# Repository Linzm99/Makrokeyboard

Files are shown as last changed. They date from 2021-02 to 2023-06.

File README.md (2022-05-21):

# Makrokeyboard
Open Source Makrokeyboard based on Atmega32U4
Image Makrokeyboard wide

## Code

The Code for the Makrokeyboard was written for the Arduino IDE, which supports the Atmega32U4 as Arduino Leonardo/Pro Micro. For uploading "Arduino Leonardo" or "Arduino (Pro) Micro" should be selected as Board. The COM Port selector will show the Atmega32U4 as well.
Hint: If your Chip wasn't flashed with a bootloader you have to do that first. This requires soldering a ISP Connector and flashing via (for example) Arduino ISP. [Tutorial from Leon Anavi](https://www.youtube.com/watch?v=ToMrxnRNHM4)

Image Makrokeyboard close

## Parts

Following Parts are required:

- 1x USB-C-Connector
- 2x 5k1 Resistor 0805
- 1x FSMD050R
- 1x 0R Resistor
- 21x SK6812 rear mounted addressable LED
- 20x Diodes 0805
- 20x Keyboard Switches
- 1x 16MHz Quarz
- 1x Atmega32U4 TQFP44
- 6x 100nF 1206
- 2x 1uF 1206
- 2x 22pF 1206
- 21x 10k Resistor 0603
- 3x 22R 1206

Image Makrokeyboard top

Created by [Linze99](https://www.twitch.tv/linze99)

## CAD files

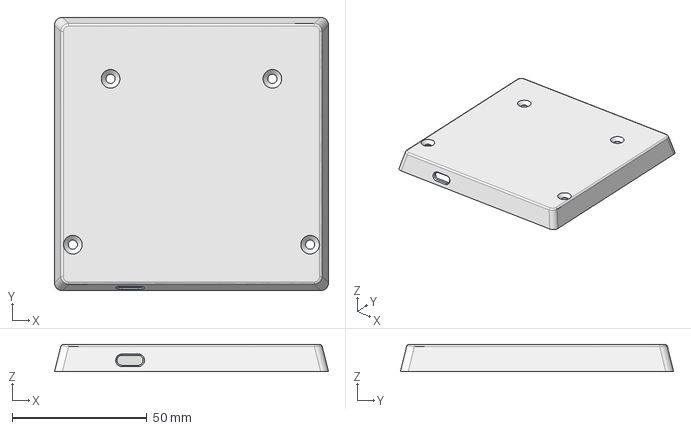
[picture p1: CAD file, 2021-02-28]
Case/gehäuse unten.FCStd
101.6 x 101.3 x 10.1 mm

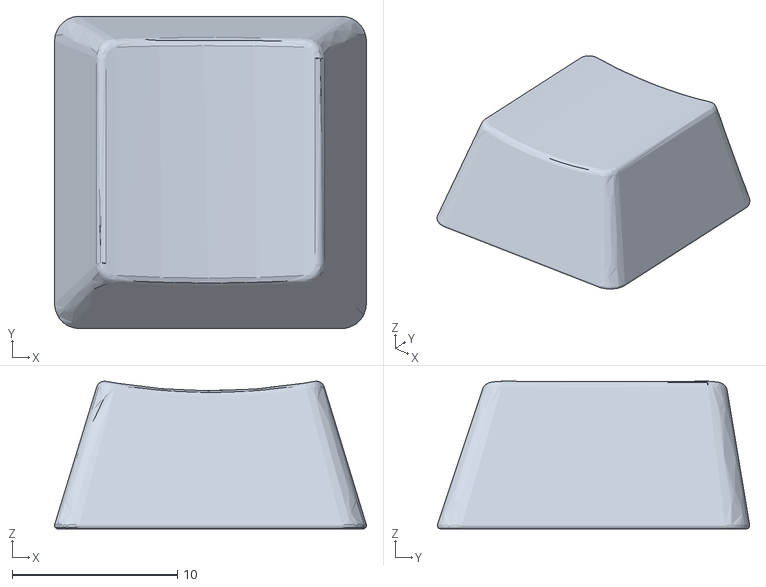
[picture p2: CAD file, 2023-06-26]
Keycaps/keycap_basic_thebrutzler.stl
18.9 x 18.9 x 8.93

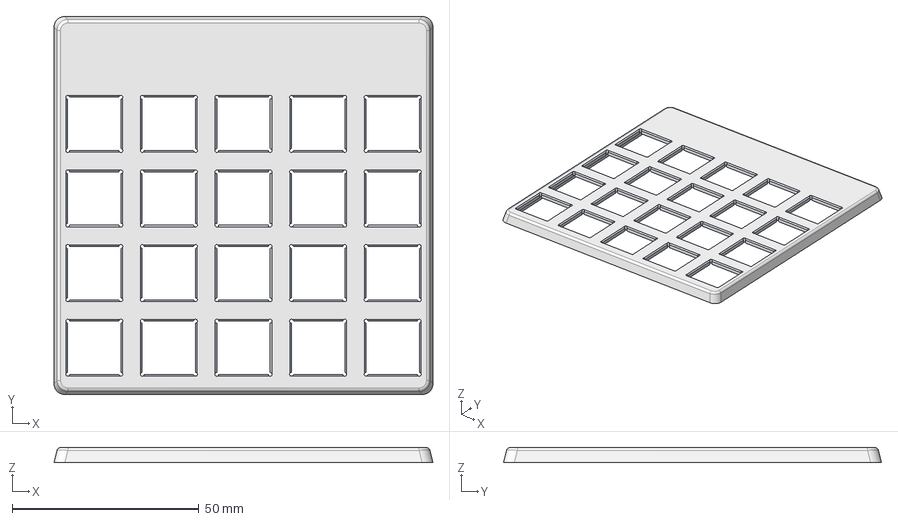
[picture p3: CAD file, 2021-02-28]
Case/Gehäuse oben.FCStd
101.6 x 101.3 x 4.00 mm

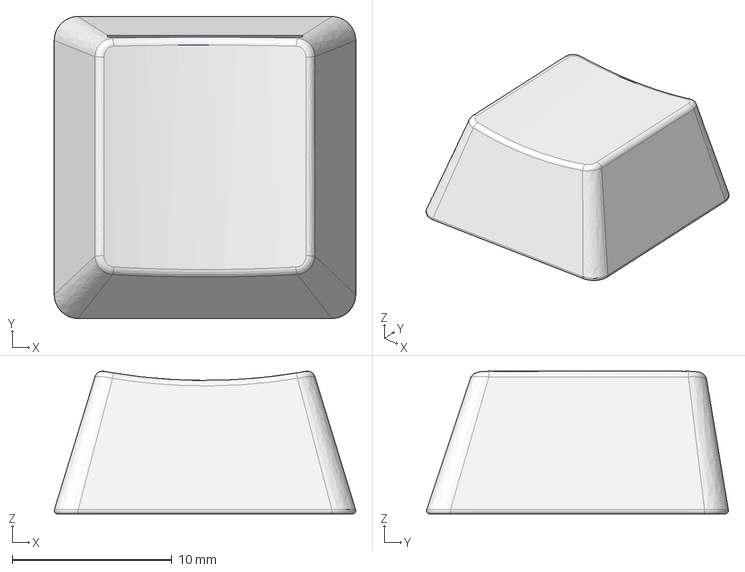
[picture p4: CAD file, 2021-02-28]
Keycaps/keycap.FCStd
18.9 x 18.9 x 8.93 mm

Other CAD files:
Keycaps/keycap_thebrutzler.FCStd
Keycaps/keycap_S1.stl
Keycaps/keycap_Loetkolben.stl
Keycaps/keycap_M2.stl
Keycaps/keycap_stop.stl
Keycaps/keycap_Lupe.stl
Keycaps/keycap_M3.stl
Keycaps/keycap_skipTrack.stl
Keycaps/keycap_1.stl
Keycaps/keycap_S4.stl
Keycaps/keycap_S2.stl
Keycaps/keycap_F.stl
Keycaps/keycap_M4.stl
Keycaps/keycap_PC.stl
Case/gehäuse_oben.stl
Case/gehäuse_unten.stl
Keycaps/keycap_M1.stl
Keycaps/keycap_S3.stl
Keycaps/keycap_Tisch.stl
Keycaps/keycap_basic.stl
Keycaps/keycap_playpause.stl
Keycaps/keycap_prevTrack.stl

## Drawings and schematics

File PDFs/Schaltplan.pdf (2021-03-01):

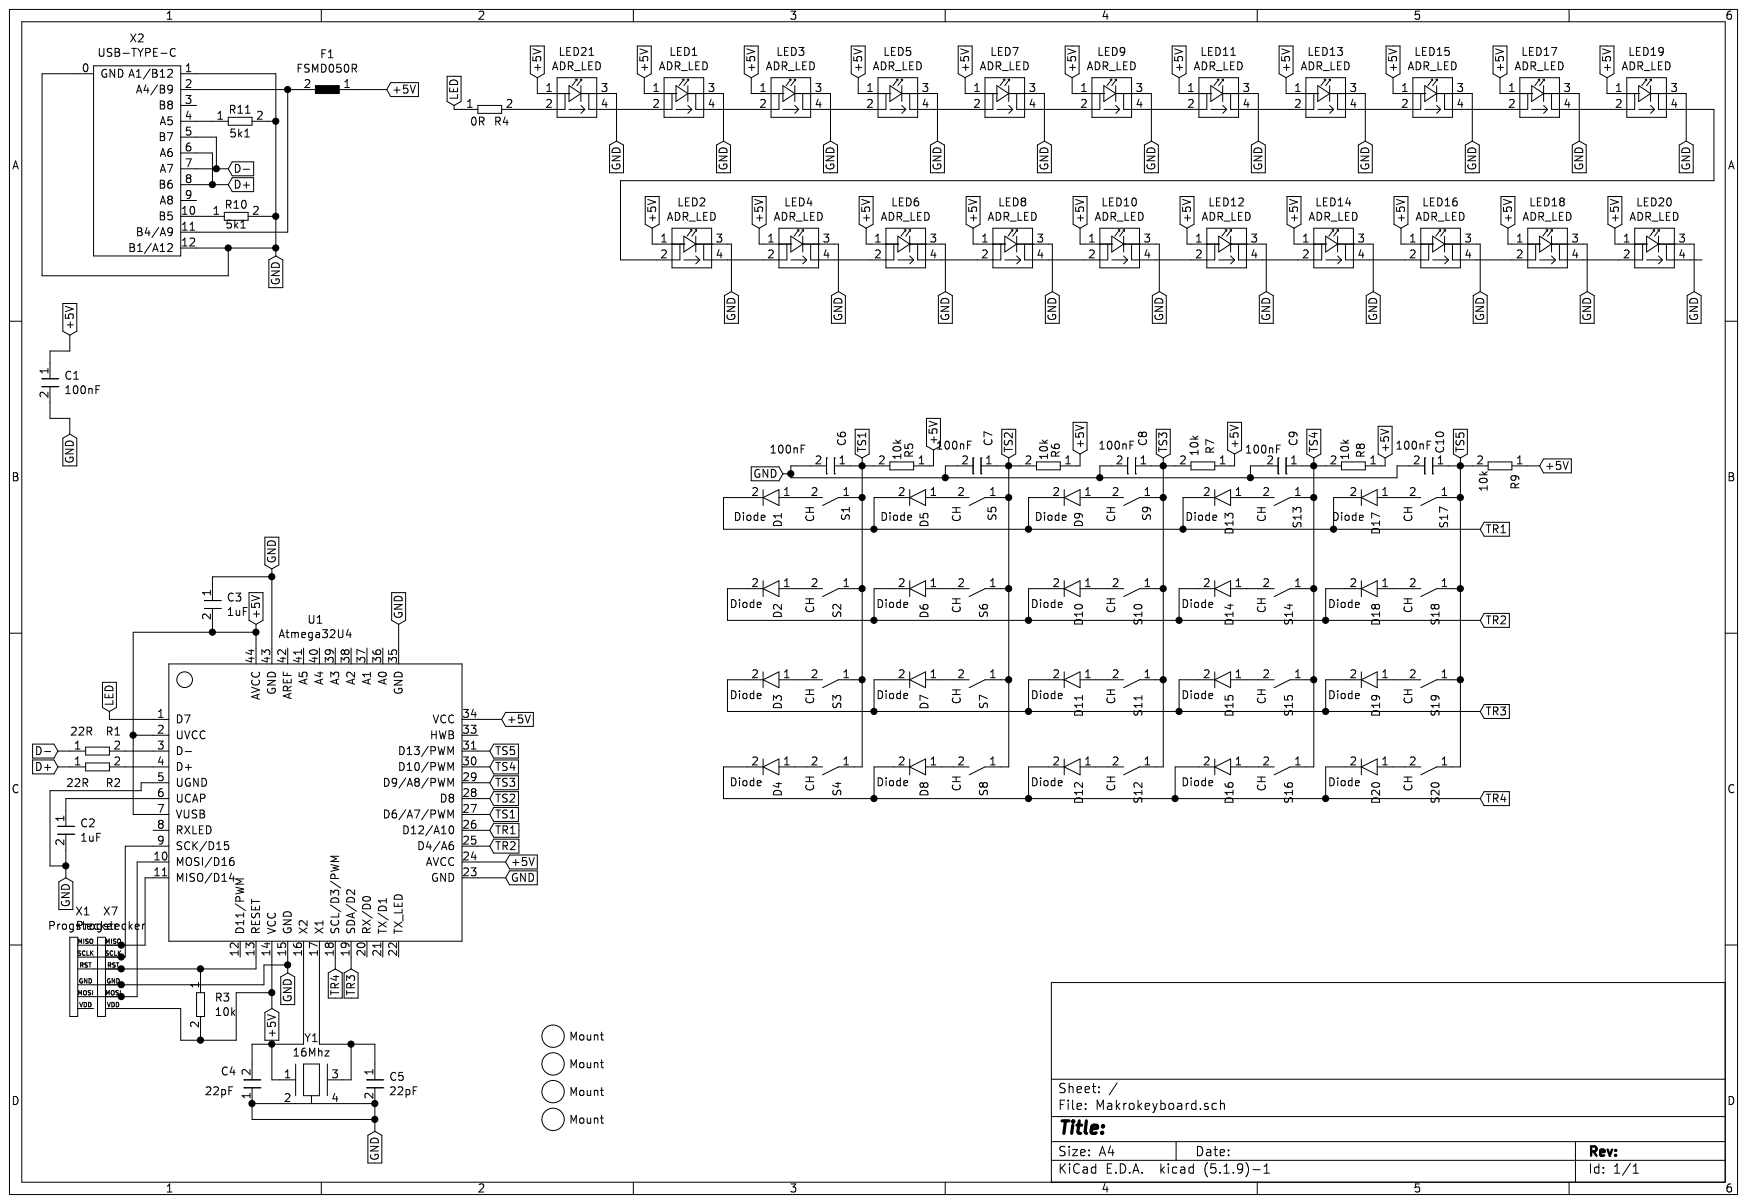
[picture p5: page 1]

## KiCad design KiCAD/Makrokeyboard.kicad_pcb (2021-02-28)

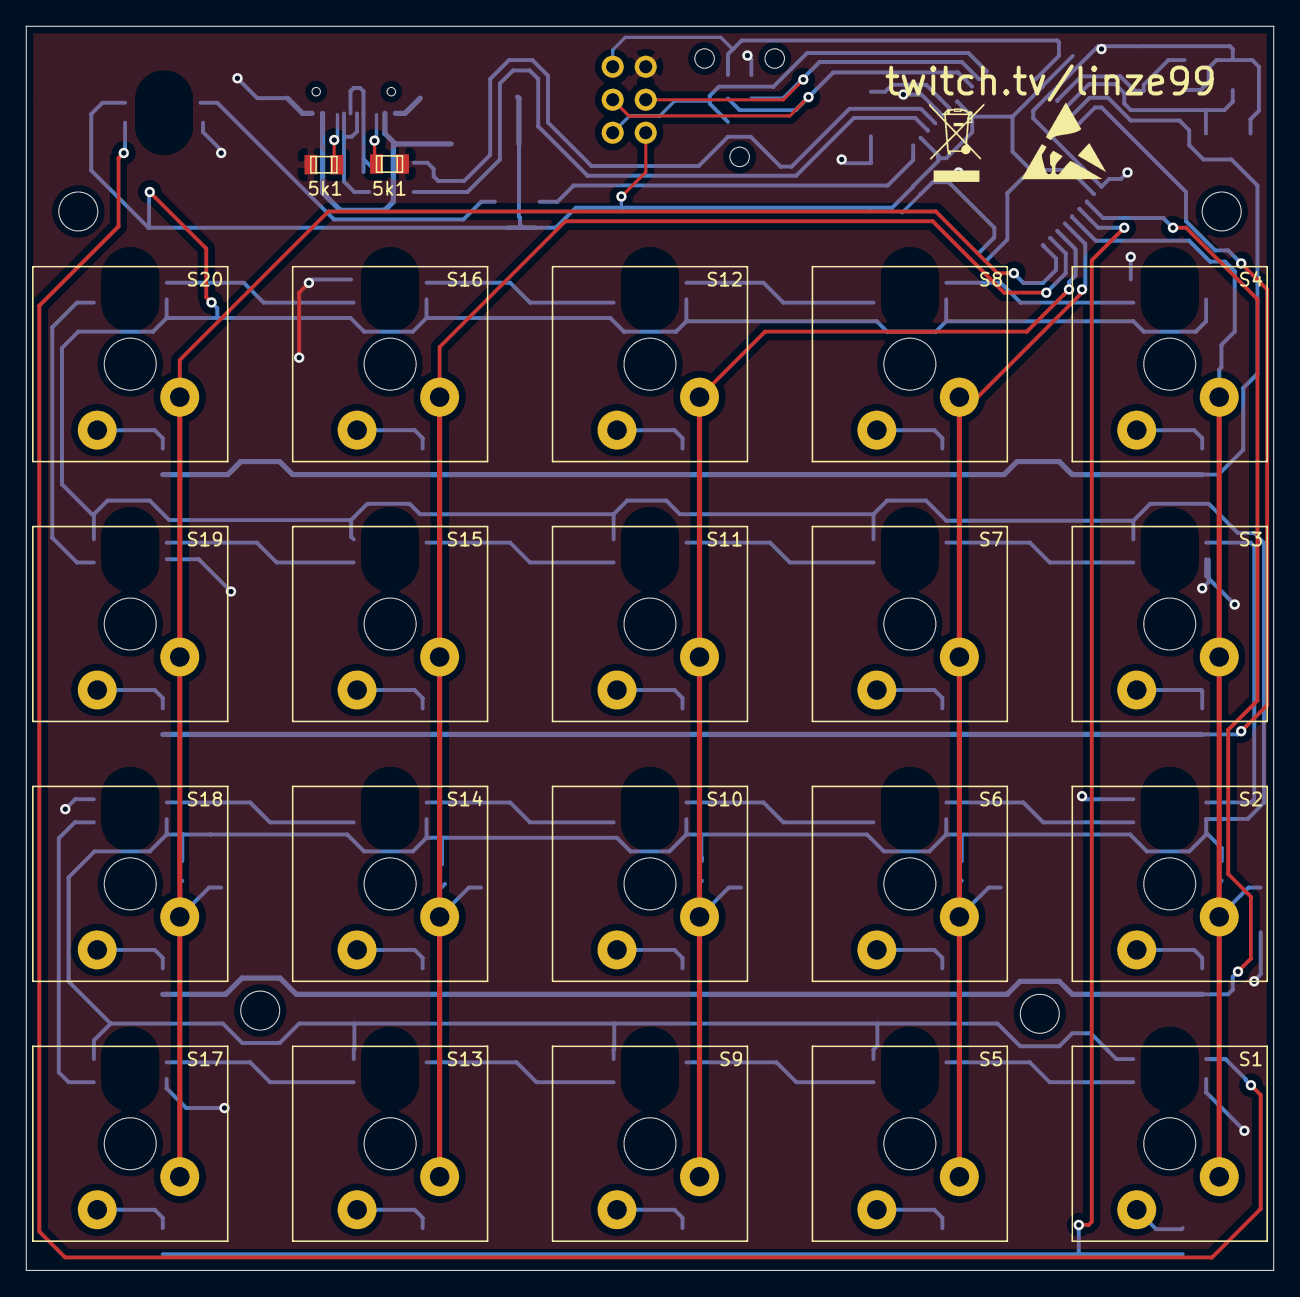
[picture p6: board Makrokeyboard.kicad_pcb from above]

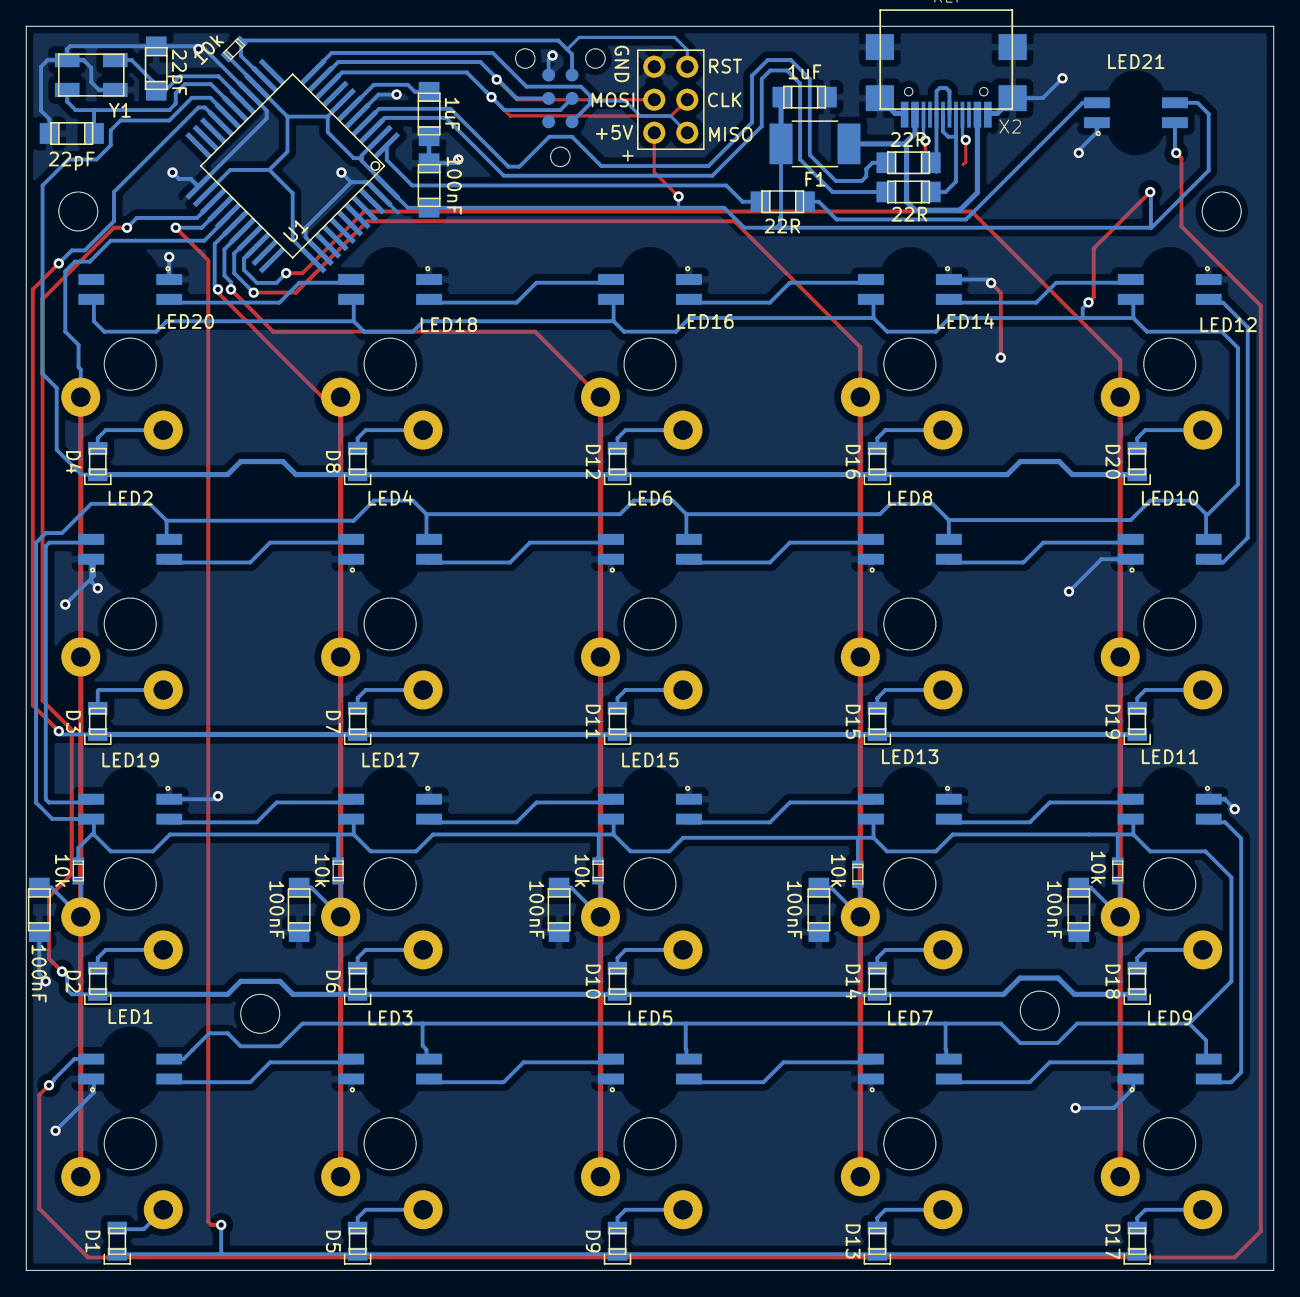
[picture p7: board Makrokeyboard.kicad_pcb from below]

Board: 2 copper layers, 96.0 x 95.8 mm, 92 parts (66 on the bottom side), 67 nets.

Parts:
1uF, 1uF#2: 1uF; 1206
5k1, 5k1#2: 5k1; 0805
10k, 10k#2, 10k#3, 10k#4, 10k#5, 10k#6: 10k; 0603
22R: 0R; 1206
22R#2, 22R#3: 22R; 1206
22pF, 22pF#2: 22pF; 1206
100nF, 100nF#2, 100nF#3, 100nF#4, 100nF#5, 100nF#6: 100nF; 1206
D1, D2, D3, D4, D5, D6, D7, D8, D9, D10, D11, D12, D13, D14, D15, D16, D17, D18, D19, D20: Diode; 0805d
F1: FSMD050R; 1812
LED1, LED2, LED3, LED4, LED5, LED6, LED7, LED8, LED9, LED10, LED11, LED12, LED13, LED14, LED15, LED16, LED17, LED18, LED19, LED20, LED21: ADR_LED; SK6812r
S1, S2, S3, S4, S5, S6, S7, S8, S9, S10, S11, S12, S13, S14, S15, S16, S17, S18, S19, S20: CH; CHERRYMX
U1: Atmega32U4; TQFP44
X1: Progstecker
X2: *REF; USB-TYPE-C
X3, X4, X5, X6: Mount; Mount3mm
X7: Progstecker; Progstecker_alt
Y1: 16Mhz; SMD_Crystal

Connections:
+5V: 1uF.2, 10k.1, 10k#2.1, 10k#3.1, 10k#4.1, 10k#5.1, 10k#6.2, 100nF#6.1, F1.1, LED1.1, LED2.1, LED3.1, LED4.1, LED5.1, LED6.1, LED7.1, LED8.1, LED9.1, LED10.1, LED11.1, LED12.1, LED13.1, LED14.1, LED15.1, LED16.1, LED17.1, LED18.1, LED19.1, LED20.1, LED21.1, U1.2, U1.7, U1.14, U1.24, U1.34, U1.44, X7.VDD
D+: 22R#2.1, X2.6, X2.8
D-: 22R#3.1, X2.5, X2.7
GND: 1uF.1, 1uF#2.2, 5k1.2, 5k1#2.2, 22pF.2, 22pF#2.1, 100nF.2, 100nF#2.2, 100nF#3.2, 100nF#4.2, 100nF#5.2, 100nF#6.2, LED1.3, LED2.3, LED3.3, LED4.3, LED5.3, LED6.3, LED7.3, LED8.3, LED9.3, LED10.3, LED11.3, LED12.3, LED13.3, LED14.3, LED15.3, LED16.3, LED17.3, LED18.3, LED19.3, LED20.3, LED21.3, U1.5, U1.15, U1.23, U1.35, U1.43, X1.GND, X2.0, X2.1, X2.12, X7.GND, Y1.2, Y1.4
LED: 22R.1, U1.1
unnamed: 1uF#2.1, U1.6
unnamed: 22pF#2.2, U1.16, Y1.1
unnamed: 22pF.1, U1.17, Y1.3
unnamed: D1.1, S1.2
unnamed: D2.1, S2.2
unnamed: D3.1, S3.2
unnamed: D4.1, S4.2
unnamed: D5.1, S5.2
unnamed: D6.1, S6.2
unnamed: D7.1, S7.2
unnamed: D8.1, S8.2
unnamed: D9.1, S9.2
unnamed: D10.1, S10.2
unnamed: D11.1, S11.2
unnamed: D12.1, S12.2
unnamed: D13.1, S13.2
unnamed: D14.1, S14.2
unnamed: D15.1, S15.2
unnamed: D16.1, S16.2
unnamed: D17.1, S17.2
unnamed: D18.1, S18.2
unnamed: D19.1, S19.2
unnamed: D20.1, S20.2
unnamed: F1.2, X2.2, X2.11
unnamed: LED1.2, LED21.4
unnamed: LED1.4, LED3.2
unnamed: LED2.4, LED4.2
unnamed: LED3.4, LED5.2
unnamed: LED4.4, LED6.2
unnamed: LED5.4, LED7.2
unnamed: LED6.4, LED8.2
unnamed: LED7.4, LED9.2
unnamed: LED8.4, LED10.2
unnamed: LED10.4, LED12.2
unnamed: LED9.4, LED11.2
unnamed: LED11.4, LED13.2
unnamed: LED12.4, LED14.2
unnamed: LED13.4, LED15.2
unnamed: LED14.4, LED16.2
unnamed: LED15.4, LED17.2
unnamed: LED16.4, LED18.2
unnamed: LED17.4, LED19.2
unnamed: LED18.4, LED20.2
unnamed: LED2.2, LED19.4
unnamed: 22R.2, LED21.2
unnamed: 22R#3.2, U1.3
unnamed: 22R#2.2, U1.4
unnamed: 10k#6.1, U1.13, X1.RST, X7.RST
unnamed: 5k1#2.1, X2.10
unnamed: 5k1.1, X2.4
unnamed: U1.9, X1.SCLK, X7.SCLK
unnamed: U1.10, X1.MOSI, X7.MOSI
unnamed: U1.11, X1.MISO, X7.MISO
TR1: D1.2, D5.2, D9.2, D13.2, D17.2, U1.26
TR2: D2.2, D6.2, D10.2, D14.2, D18.2, U1.25
TR3: D3.2, D7.2, D11.2, D15.2, D19.2, U1.19
TR4: D4.2, D8.2, D12.2, D16.2, D20.2, U1.18
TS1: 10k#5.2, 100nF#5.1, S1.1, S2.1, S3.1, S4.1, U1.27
TS2: 10k#4.2, 100nF#4.1, S5.1, S6.1, S7.1, S8.1, U1.28
TS3: 10k#3.2, 100nF#3.1, S9.1, S10.1, S11.1, S12.1, U1.29
TS4: 10k#2.2, 100nF#2.1, S13.1, S14.1, S15.1, S16.1, U1.30
TS5: 10k.2, 100nF.1, S17.1, S18.1, S19.1, S20.1, U1.31

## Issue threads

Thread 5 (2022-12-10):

testissue

ReskQ, 2022-12-10:
<!-- Bearbeiten Sie den Text des neuen Problems, und klicken Sie dann auf ✓ „Problem erstellen“ in der oberen rechten Ecke des Editors. Die erste Zeile wird der Titel des Problems sein. Zugewiesene Personen und Beschriftungen folgen nach einer leeren Zeile. Belassen Sie eine leere Zeile, bevor Sie mit dem Text des Problems beginnen. -->

Closed 2023-06-26.

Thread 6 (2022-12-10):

testtest

ReskQ, 2022-12-10:
<!-- Bearbeiten Sie den Text des neuen Problems, und klicken Sie dann auf ✓ „Problem erstellen“ in der oberen rechten Ecke des Editors. Die erste Zeile wird der Titel des Problems sein. Zugewiesene Personen und Beschriftungen folgen nach einer leeren Zeile. Belassen Sie eine leere Zeile, bevor Sie mit dem Text des Problems beginnen. -->

Linzm99, 2022-12-10:
Was gibts?

ReskQ, 2022-12-10:
Hi, Linze habs erblickt mit dem Git ;-) wollte das Issue bei mir erstellen.... bzw testen

Closed 2023-06-26.

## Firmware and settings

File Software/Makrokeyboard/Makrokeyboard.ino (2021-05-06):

#include <Adafruit_NeoPixel.h>
#include <Keyboard.h>

//defines for LEDS
#define FADE 1


//defines for I/Os
#define TS1 6
#define TS2 8
#define TS3 9
#define TS4 10
#define TS5 5

#define TR1 12
#define TR2 4
#define TR3 2
#define TR4 3

#define KEY_SPACE 32

uint8_t rows[4] = {TR4, TR3, TR2, TR1};
uint8_t cols[5] = {TS5, TS4, TS3, TS2, TS1};


//F-Keys
char key[4][5] = {{(char)KEY_F1, (char)KEY_F2, (char)KEY_F3, (char)KEY_F4, (char)KEY_F5},
                  {(char)KEY_F6, (char)KEY_F7, (char)KEY_F8, (char)KEY_F9, (char)KEY_F10},
                  {(char)KEY_F11, (char)KEY_F12, (char)KEY_F13, (char)KEY_F14, (char)KEY_F15},                    
                  {(char)KEY_F16, (char)KEY_F17, (char)KEY_F18, (char)KEY_F19, (char)KEY_F20}};                    

//Key Mask for second Key
char mask[4][5] = {{(char)KEY_LEFT_CTRL, (char)KEY_LEFT_CTRL, (char)KEY_LEFT_CTRL, (char)KEY_LEFT_CTRL, (char)KEY_LEFT_CTRL},
                   {(char)KEY_LEFT_CTRL, (char)KEY_LEFT_CTRL, (char)KEY_LEFT_CTRL, (char)KEY_LEFT_CTRL, (char)KEY_LEFT_CTRL},
                   {(char)KEY_LEFT_CTRL, (char)KEY_LEFT_CTRL, (char)KEY_LEFT_CTRL, (char)KEY_LEFT_CTRL, (char)KEY_LEFT_CTRL},                    
                   {(char)KEY_LEFT_CTRL, (char)KEY_LEFT_CTRL, (char)KEY_LEFT_CTRL, (char)KEY_LEFT_CTRL, (char)KEY_LEFT_CTRL}};            

//Key Mask for third Key
char mask2[4][5] = {{(char)KEY_LEFT_SHIFT, (char)KEY_LEFT_SHIFT, (char)KEY_LEFT_SHIFT, (char)KEY_LEFT_SHIFT, (char)KEY_LEFT_SHIFT},
                    {(char)KEY_LEFT_SHIFT, (char)KEY_LEFT_SHIFT, (char)KEY_LEFT_SHIFT, (char)KEY_LEFT_SHIFT, (char)KEY_LEFT_SHIFT},
                    {(char)KEY_LEFT_SHIFT, (char)KEY_LEFT_SHIFT, (char)KEY_LEFT_SHIFT, (char)KEY_LEFT_SHIFT, (char)KEY_LEFT_SHIFT},                    
                    {(char)KEY_LEFT_SHIFT, (char)KEY_LEFT_SHIFT, (char)KEY_LEFT_SHIFT, (char)KEY_LEFT_SHIFT, (char)KEY_LEFT_SHIFT}};

//Mask for Strings
String str_mask[4][5] = {{"","","","",""},
                         {"","","","",""},
                         {"","","","",""},
                         {"","","","",""}};
                         
//Mask for selecting Key Behaviour :
//0: Regular key behaviour with masks
//1: Single key stroke of "Key" Matrix
//2: Print String from String Mask

char press_once[4][5] = {{0,0,0,0,0},
                         {0,0,0,0,0},
                         {0,0,0,0,0},                    
                         {0,0,0,0,0}};


//Led Maps for different Patterns
uint8_t led_map_default[4][5] = {{16,17,18,19,20},
                                 {15,14,13,12,11},
                                 {6,7,8,9,10},                    
                                 {5,4,3,2,1}};

uint8_t led_map_horz[21] = {16,17,18,19,20,15,14,13,12,11,6,7,8,9,10,5,4,3,2,1,0};
uint8_t led_map_diag[21] = {16,15,17,6,14,18,5,7,13,19,4,8,12,20,3,9,11,2,10,1,0};

//Buffer for pressed Keys
uint8_t key_buffer[4][5] = {0};


//Variables for RGB keys
char PIN = 7;
int NUMPIXELS = 21; 
unsigned int countges = 0;

unsigned int RES = 600;

int phaseshift = RES/90;

int adcval = 0;

int colorstato = 0;
int counter = 0;

int last_key = -1;
int fade_out = 0;


//Functions:

void RGB_Simple(uint8_t r, uint8_t g, uint8_t b);
void RGB_Solid_Single(uint16_t val);
void RGB_Solid_Rows(uint16_t val);
void RGB_Solid_Cols(uint16_t val);
void key_flash(void);
void key_wave(void);
void RGB_Fade_Diag(void);

void get_keys(void){
  for(uint8_t i = 0; i<4; i++){
    digitalWrite(rows[i], LOW);
    for(uint8_t j = 0; j<5; j++){
      delay(1);
      if(!digitalRead(cols[j])){
        if(key_buffer[i][j] == 0){
          key_handle(i,j,1);
          fade_out = 255;
        }
        key_buffer[i][j] = 1;
        last_key = led_map_default[i][j];
        Serial.println(fade_out);
        
      }
      else{
        if(key_buffer[i][j] == 1){
          key_handle(i,j,0);
        }
        key_buffer[i][j] = 0;
      }
    }
    digitalWrite(rows[i], HIGH);
  }

}





void key_handle(uint8_t x, uint8_t y, uint8_t z){
  if(z == 1){
    if(press_once[x][y] == 0){
      if(mask[x][y]!= 0){
        Keyboard.press(mask[x][y]);
      }
      if(mask2[x][y]!= 0){
        Keyboard.press(mask2[x][y]);
      }
      Keyboard.press(key[x][y]);
    }
    else if(press_once[x][y] == 2){
      Keyboard.print(str_mask[x][y]);
    }
    else{
      Keyboard.print(key[x][y]);
    }
  }
  else{
    if(press_once[x][y] == 0){
      if(mask[x][y]!= 0){
        Keyboard.release(mask[x][y]);
      }
      if(mask2[x][y]!= 0){
        Keyboard.release(mask2[x][y]);
      }
      Keyboard.release(key[x][y]);
    }
  }
  
}


unsigned char color_r(unsigned int count){
  if(count >= 0 && count < RES/3){
    return (int)(255*count/(RES/3));
  }
  else if (count >=(RES/3) && count < (2*RES/3)){
    return (int)(510-(255*count/(RES/3)));
  }
  else if(count >= RES && count < (RES+(RES/3))){
    return (int)(255*(count-RES)/(RES/3));
  }
  else if (count >=RES+(RES/3) && count <RES+(2*RES/3)){
    return (int)(510-(255*(count-RES)/(RES/3)));
  }
  else{
    return 0;
  }
  
}

unsigned char color_g(unsigned int count){
  
  if (count >=(RES/3) && count <(2*RES/3)){
    return (int)((255*(count-(RES/3))/(RES/3)));
  }
  else if (count >=(2*RES/3) && count <=(RES)){
    return (int)(510-(255*(count-(RES/3))/(RES/3)));
  }
  else if (count >=RES + (RES/3) && count <RES +(2*RES/3)){
    return (int)((255*(count-(RES/3)-RES)/(RES/3)));
  }
  else if (count >= RES + (2*RES/3) && count <= RES+ (RES)){
    return (int)(510-(255*(count-(RES/3)-RES)/(RES/3)));
  }
  else{
    return 0;
  }
  
}

unsigned char color_b(unsigned int count){
  if(count >= 0 && count < (RES/3)){
    return (int)(255-(255*count/(RES/3)));
  }
  else if (count >=(2*RES/3) && count <(RES)){
    return (int)((255*(count-(2*RES/3))/(RES/3)));
  }
  else if(count >= RES && count < RES+(RES/3)){
    return (int)(255-(255*(count-RES)/(RES/3)));
  }
  else if (count >=RES +(2*RES/3) && count <2*(RES)){
    return (int)((255*(count-(2*RES/3)-RES)/(RES/3)));
  }
  
  else{
    return 0;
  }
  
}



Adafruit_NeoPixel led = Adafruit_NeoPixel(NUMPIXELS, PIN, NEO_GRB + NEO_KHZ800);


//Lighting Wave Pattern
void key_wave(void){
  led.clear();
  static uint8_t bright[4][5] = {{50,50,50,50,50},
                                 {50,50,50,50,50},
                                 {50,50,50,50,50},                    
                                 {50,50,50,50,50}};
  static uint8_t spread[4][5] = {0};
  static uint8_t was_pressed[4][5] = {0};
  for(int i = 0; i < 4; i++){
    for(int j = 0; j < 5; j++){
      if(key_buffer[i][j]){
        if(spread[i][j] == 0){
          spread[i][j] = 50;
        }
        else if(was_pressed[i][j] == 0){
          spread[i][j] = 40;
        }
        was_pressed[i][j] = 1;
        
      }
      else{
        was_pressed[i][j] = 0;
      }
      if(spread[i][j] > 0){
        for(int h = 0; h<4; h++){
          for(int k = 0; k<5; k++){
            float dist = sqrt(abs(h-i) + abs(k-j));
            if(-(spread[i][j]-50)>=(dist*3)){
              bright[h][k] = (uint8_t)((bright[h][k] + 50 - spread[i][j]*2*sin((spread[i][j]-50)*0.4 + dist) + 100)/2);
            }
            else{
              bright[h][k] = 50;
            }
          }
        }
        spread[i][j]--;
      }
      
      led.setPixelColor(led_map_default[i][j],0,(uint8_t)((bright[i][j])*0.5),bright[i][j]);
    }
  }
  led.show();
}


//Show Single RGB Colour on the whole Keyboard
void RGB_Simple(uint8_t r, uint8_t g, uint8_t b){
  led.setBrightness(50);
  for(int i = 0; i< NUMPIXELS;++i){
    led.setPixelColor(led_map_diag[i],r,g,b);
    
  }
  led.show();
}

//Keys falsh up and fade after a short period of time
void key_flash_fade(void){
  static uint8_t bright[4][5] = {0};
  led.clear();
  for(int i = 0; i < 5; i++){
    for(int j = 0; j < 4; j++){
      if(key_buffer[i][j]){
        led.setPixelColor(led_map_default[i][j],255,255,255);
        bright[i][j] = 255;
        
      }
      else{
        if(bright[i][j]){
          led.setPixelColor(led_map_default[i][j],bright[i][j],bright[i][j],bright[i][j]);
          bright[i][j] -= 5;
        }
      }
      
    }
  }
  led.show();
}


//Keys light up while beeign held down
void key_flash(void){
  led.clear();
  for(int i = 0; i < 5; i++){
    for(int j = 0; j < 4; j++){
      if(key_buffer[i][j]){
        led.setPixelColor(led_map_default[i][j],255,255,255);
        
      }
      
    }
  }
  led.show();
}


//All keys have a slight colour fade across the Keyboard starting at Val
void RGB_Solid(uint16_t val){
  led.setBrightness(50);
  for(int i = 0; i< NUMPIXELS;++i){
    if(last_key != led_map_diag[i]){      
      const int HYS = 50;
      const int MIN = 0 + HYS;
      const int MAX = 255- HYS;
      int RED = color_r((val + i*phaseshift)%RES);
      if(RED<=MIN)
        RED = MIN;
      if(RED>=MAX)
        RED = MAX;
      int BLUE = color_b((val + i*phaseshift)%RES);
      if(BLUE<=MIN)
        BLUE = MIN;
      if(BLUE>=MAX)
        BLUE = MAX;
      int GREEN = color_g((val + i*phaseshift)%RES);
      if(GREEN<=MIN)
        GREEN = MIN;
      if(GREEN>=MAX)
        GREEN = MAX;
      led.setPixelColor(led_map_diag[i],RED,BLUE,GREEN);
    } else if(FADE){
      led.setPixelColor(led_map_diag[i],(int)((fade_out+color_r((val + i*phaseshift)%RES))/(2.0-(255-fade_out)/255)),(int)((fade_out+color_g((val + i*phaseshift)%RES))/(2.0-(255-fade_out)/255)),(int)((fade_out+color_b((val + i*phaseshift)%RES))/(2.0-(255-fade_out)/255)));

    } else {
      led.setPixelColor(led_map_diag[i],255,255,255);
    }
  }
  led.show();
}


//Fade between rows
void RGB_Solid_Rows(uint16_t val){
  led.setBrightness(50);
  for(int i = 0; i< 4;++i){
    led.setPixelColor(led_map_horz[(i*5)],color_r((val + i*phaseshift)%RES),color_g((val + i*phaseshift)%RES),color_b((val + i*phaseshift)%RES));
    led.setPixelColor(led_map_horz[(i*5)+1],color_r((val + i*phaseshift)%RES),color_g((val + i*phaseshift)%RES),color_b((val + i*phaseshift)%RES));
    led.setPixelColor(led_map_horz[(i*5)+2],color_r((val + i*phaseshift)%RES),color_g((val + i*phaseshift)%RES),color_b((val + i*phaseshift)%RES));
    led.setPixelColor(led_map_horz[(i*5)+3],color_r((val + i*phaseshift)%RES),color_g((val + i*phaseshift)%RES),color_b((val + i*phaseshift)%RES));
    led.setPixelColor(led_map_horz[(i*5)+4],color_r((val + i*phaseshift)%RES),color_g((val + i*phaseshift)%RES),color_b((val + i*phaseshift)%RES));
    
  }
  led.show();
}

//Fade between Cols
void RGB_Solid_Cols(uint16_t val){
  led.setBrightness(50);
  for(int i = 0; i< 5;++i){
    led.setPixelColor(led_map_horz[i],color_r((val + i*phaseshift)%RES),color_g((val + i*phaseshift)%RES),color_b((val + i*phaseshift)%RES));
    led.setPixelColor(led_map_horz[i+5],color_r((val + i*phaseshift)%RES),color_g((val + i*phaseshift)%RES),color_b((val + i*phaseshift)%RES));
    led.setPixelColor(led_map_horz[i+10],color_r((val + i*phaseshift)%RES),color_g((val + i*phaseshift)%RES),color_b((val + i*phaseshift)%RES));
    led.setPixelColor(led_map_horz[i+15],color_r((val + i*phaseshift)%RES),color_g((val + i*phaseshift)%RES),color_b((val + i*phaseshift)%RES)); 
  }
  led.show();
}

void RGB_Fade_Diag(void){
  led.setBrightness(50);
  for(int i = 0; i< NUMPIXELS;++i){
    led.setPixelColor(led_map_diag[i],color_r((countges + i*phaseshift)%RES),color_g((countges + i*phaseshift)%RES),color_b((countges + i*phaseshift)%RES));
  }
  led.show();
  if (countges < RES){
    countges ++;
  }
  else{
    countges = 0;
  }
}

void setup() {
  //Initializing all I/Os
  led.clear();
  led.begin();
  led.setBrightness(50);
  pinMode(TR1, OUTPUT);
  pinMode(TR2, OUTPUT);
  pinMode(TR3, OUTPUT);
  pinMode(TR4, OUTPUT);
  pinMode(TS1, INPUT);
  pinMode(TS2, INPUT);
  pinMode(TS3, INPUT);
  pinMode(TS4, INPUT);
  pinMode(TS5, INPUT);
  digitalWrite(TR1, LOW);
  digitalWrite(TR2, LOW);
  digitalWrite(TR3, LOW);
  digitalWrite(TR4, LOW);
  led.show();
  Keyboard.begin();
  delay(10);
  RGB_Solid(600);
  
  
}

//Main loop
uint16_t leds;
void loop() {
    


  get_keys();
 
  RGB_Solid(leds++);
  if(FADE){
    if(fade_out <= 0){
      last_key = -1;
    }
    else{
      fade_out--;
    }
  }
  
  

}

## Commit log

2021-02-28 Initial Upload
    [Gehäuse oben.FCStd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]
2021-03-17 Tasten haben Defaults, letzte Taste hat Highlight
    Die Tasten haben STRG + Shift + F1 - F20 als Key
    Die zuletzt gedrückte Taste bleibt weiß
    Andere Tasten faden durch die Farben
2021-05-06 Update Makrokeyboard.ino
    Kontrastwechsel der Farben angepasst.
2021-06-28 add hole and clamp
    add hole to fit better on switches
    add clamp to tighten keycap on switch
    [keycap_basic_thebrutzler.stl, keycap_thebrutzler.FCStd]
2022-05-21 Update README.md
    Board corrected
